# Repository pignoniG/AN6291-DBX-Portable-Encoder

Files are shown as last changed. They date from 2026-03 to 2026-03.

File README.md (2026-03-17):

AN6291 based DBX Portable Encoder with premplifier for electrect micropones.
Beware, for reliability (aka avoid switches), this can only perform as an encoder.

BOM -> https://pignonig.github.io/AN6291-DBX-Portable-Encoder/AN6291_encoder/bom/ibom.html

Online kikad visualization -> https://kicanvas.org/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

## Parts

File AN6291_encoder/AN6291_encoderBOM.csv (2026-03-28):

Reference | Qty | Value | JLCPCB Part | Footprint | Datasheet
C7,C16 | 2 | 330pf |  | Capacitor_SMD:C_0805_2012Metric | ~
C25,C31 | 2 | 2.7nF |  | Capacitor_SMD:C_0805_2012Metric | ~
C8,C9,C14,C15 | 4 | 3.3nf |  | Capacitor_SMD:C_0805_2012Metric | ~
C23,C26,C28,C32 | 4 | 6.8nf |  | Capacitor_SMD:C_0805_2012Metric | ~
C20,C22 | 2 | 10nf |  | Capacitor_SMD:C_0805_2012Metric | ~
C5,C18,C19,C21 | 4 | 33nf |  | Capacitor_SMD:C_0805_2012Metric | ~
C27,C29 | 2 | 0.1uf |  | Capacitor_SMD:C_1206_3216Metric | ~
C46,C47 | 2 | 100nf |  | Capacitor_SMD:C_1206_3216Metric | ~
C10,C11,C12,C13 | 4 | 100n |  | Capacitor_SMD:C_1206_3216Metric | ~
C6,C17 | 2 | 0.47uf |  | Capacitor_SMD:C_1206_3216Metric | ~
C4 | 1 | 1uf |  | Capacitor_SMD:C_0805_2012Metric | ~
C1,C2,C39,C40,C43,C44 | 6 | 10uf |  | Capacitor_SMD:C_1206_3216Metric | ~
C3,C33,C34,C35,C36,C38,C41,C42,C45,C50 | 10 | 10uf |  | Capacitor_SMD:C_0805_2012Metric | ~
C24,C30 | 2 | 22uf |  | Capacitor_SMD:C_1206_3216Metric | ~
C37 | 1 | 100uf |  | Capacitor_THT:CP_Radial_D10.0mm_P5.00mm | ~
R37,R48,R49,R58,R59,R60,R61 | 7 | 100R | C17408 | Resistor_SMD:R_0805_2012Metric | ~
R33,R35,R40,R42 | 4 | 270R | C17590 | Resistor_SMD:R_0805_2012Metric | ~
R22,R29 | 2 | 330R | C17630 | Resistor_SMD:R_0805_2012Metric | ~
R20,R21 | 2 | 560R | C28636 | Resistor_SMD:R_0805_2012Metric | ~
R1,R2,R19 | 3 | 1k | C17513 | Resistor_SMD:R_0805_2012Metric | ~
R64,R65 | 2 | 1k | C17513 | Resistor_SMD:R_0805_2012Metric | ~
R36,R41 | 2 | 2k | C17604 | Resistor_SMD:R_0805_2012Metric | ~
RV1 | 1 | 2k |  | Potentiometer_SMD:Potentiometer_Vishay_TS53YL_Vertical | ~
R4,R17 | 2 | 3.3K | C26010 | Resistor_SMD:R_0805_2012Metric | ~
R8,R14,R50,R53 | 4 | 4.7k | C17673 | Resistor_SMD:R_0805_2012Metric | ~
R6,R16 | 2 | 6.8k | C17772 | Resistor_SMD:R_0805_2012Metric | ~
R3,R18 | 2 | 10k | C17414 | Resistor_SMD:R_0805_2012Metric | ~
R23,R26,R27,R32 | 4 | 15k | C17475 | Resistor_SMD:R_0805_2012Metric | ~
R30,R38 | 2 | 22k | C17560 | Resistor_SMD:R_0805_2012Metric | ~
R7,R10,R13,R15 | 4 | 33k | C17633 | Resistor_SMD:R_0805_2012Metric | ~
R24,R31 | 2 | 51k | C17737 | Resistor_SMD:R_0805_2012Metric | ~
R25,R28 | 2 | 51k | C17737 | Resistor_SMD:R_0805_2012Metric | ~
R34,R39 | 2 | 56k | C17756 | Resistor_SMD:R_0805_2012Metric | ~
R51,R52,R62,R63 | 4 | 100k | C149504 | Resistor_SMD:R_0805_2012Metric | ~
R9,R11 | 2 | 150k | C17470 | Resistor_SMD:R_0805_2012Metric | ~
R54,R55,R56,R57 | 4 | 200k | C17539 | Resistor_SMD:R_0805_2012Metric | ~
R5,R12 | 2 | 270k | C17589 | Resistor_SMD:R_0805_2012Metric | ~
J3 | 1 | batt |  | Connector_PinHeader_2.54mm:PinHeader_1x02_P2.54mm_Vertical | ~
Q3,Q6 | 2 | BC848 |  | Package_TO_SOT_SMD:SOT-23 | http://www.infineon.com/dgdl/Infineon-BC847SERIES_BC848SERIES_BC849SERIES_BC850SERIES-DS-v01_01-en.pdf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
Q4,Q5 | 2 | BCV62 |  | Package_TO_SOT_SMD:SOT-143 | https://assets.nexperia.com/documents/data-sheet/BCV62.pdf
F1 | 1 | Fuse_Small |  | Fuse:Fuse_1206_3216Metric_Pad1.42x1.75mm_HandSolder | ~
J4 | 1 | input line |  | LIB_JY039-5P__FC68133_:JY0395PFC68133 | https://www.cliffuk.co.uk/products/jacksockets/fc68131.pdf
J1 | 1 | input mic |  | LIB_JY039-5P__FC68133_:JY0395PFC68133 | https://www.cliffuk.co.uk/products/jacksockets/fc68131.pdf
H1,H2,H3,H4 | 4 | MountingHole |  | MountingHole:MountingHole_3.2mm_M3_DIN965_Pad_TopBottom | ~
Q1,Q2 | 2 | NPN |  | Package_TO_SOT_THT:TO-92 | KSC1845
U3,U4 | 2 | OPA1612AxD |  | Package_SO:SOIC-8_3.9x4.9mm_P1.27mm | http://www.ti.com/lit/ds/symlink/opa1612.pdf
J2 | 1 | output |  | Connector_Molex:Molex_KK-254_AE-6410-04A_1x04_P2.54mm_Vertical | ~
S1 | 1 | SL19-123 |  | SL19-123:SL19123 | https://www.tme.eu/Document/8790ddf534d60e194ea4328cb05e27d2/sl19123.pdf
TP1,TP3 | 2 | TestPoint |  | Connector_PinHeader_1.00mm:PinHeader_1x01_P1.00mm_Vertical | ~
U1 | 1 | ~ |  | Package_DIP:DIP-22_W10.16mm_LongPads

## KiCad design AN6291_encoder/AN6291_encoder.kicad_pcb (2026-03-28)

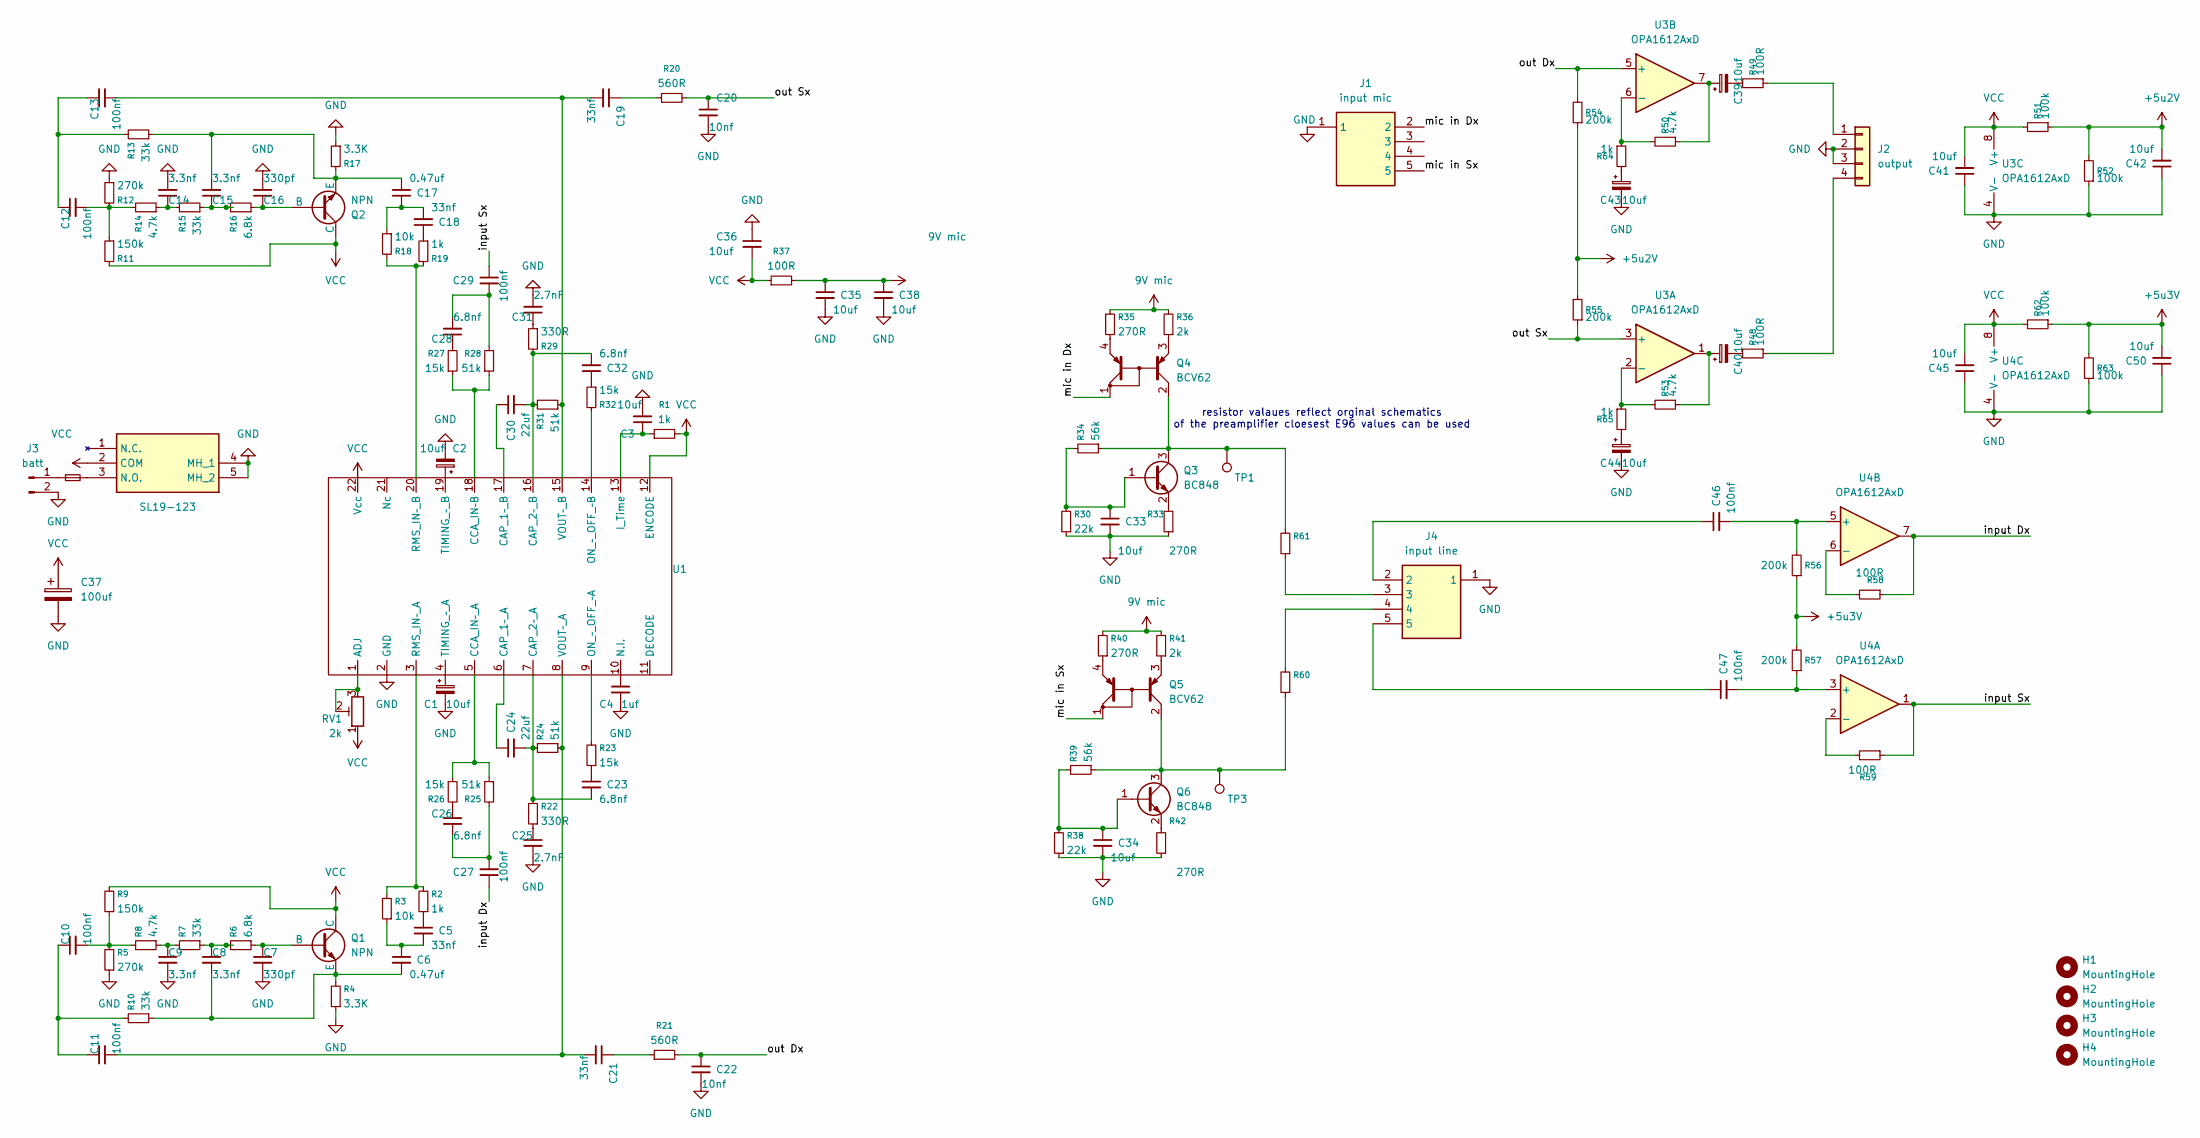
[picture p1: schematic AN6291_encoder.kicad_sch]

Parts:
C1, C2, C39, C40, C43, C44: 10uf; C_1206_3216Metric
C3, C33, C34, C35, C36, C38, C41, C42, C45, C50: 10uf; C_0805_2012Metric
C4: 1uf; C_0805_2012Metric
C5, C18, C19, C21: 33nf; C_0805_2012Metric
C6, C17: 0.47uf; C_1206_3216Metric
C7, C16: 330pf; C_0805_2012Metric
C8, C9, C14, C15: 3.3nf; C_0805_2012Metric
C10, C11, C12, C13, C27, C29, C46, C47: 100nf; C_1206_3216Metric
C20, C22: 10nf; C_0805_2012Metric
C23, C26, C28, C32: 6.8nf; C_0805_2012Metric
C24, C30: 22uf; C_1206_3216Metric
C25, C31: 2.7nF; C_0805_2012Metric
C37: 100uf; CP_Radial_D10.0mm_P5.00mm
F1: Fuse_Small; Fuse_1206_3216Metric_Pad1.42x1.75mm_HandSolder
H1, H2, H3, H4: MountingHole; MountingHole_3.2mm_M3_DIN965_Pad_TopBottom
J1: input mic; JY0395PFC68133; Manufacturer_Part_Number JY039-5P (FC68133)
J2: output; Molex_KK-254_AE-6410-04A_1x04_P2.54mm_Vertical
J3: batt; PinHeader_1x02_P2.54mm_Vertical
J4: input line; JY0395PFC68133; Manufacturer_Part_Number JY039-5P (FC68133)
Q1, Q2: NPN; TO-92
Q3, Q6: BC848; SOT-23
Q4, Q5: BCV62; SOT-143
R1, R2, R19, R64, R65: 1k; R_0805_2012Metric; JLCPCB Part C17513
R3, R18: 10k; R_0805_2012Metric; JLCPCB Part C17414
R4, R17: 3.3K; R_0805_2012Metric; JLCPCB Part C26010
R5, R12: 270k; R_0805_2012Metric; JLCPCB Part C17589
R6, R16: 6.8k; R_0805_2012Metric; JLCPCB Part C17772
R7, R10, R13, R15: 33k; R_0805_2012Metric; JLCPCB Part C17633
R8, R14, R50, R53: 4.7k; R_0805_2012Metric; JLCPCB Part C17673
R9, R11: 150k; R_0805_2012Metric; JLCPCB Part C17470
R20, R21: 560R; R_0805_2012Metric; JLCPCB Part C28636
R22, R29: 330R; R_0805_2012Metric; JLCPCB Part C17630
R23, R26, R27, R32: 15k; R_0805_2012Metric; JLCPCB Part C17475
R24, R25, R28, R31: 51k; R_0805_2012Metric; JLCPCB Part C17737
R30, R38: 22k; R_0805_2012Metric; JLCPCB Part C17560
R33, R35, R40, R42: 270R; R_0805_2012Metric; JLCPCB Part C17590
R34, R39: 56k; R_0805_2012Metric; JLCPCB Part C17756
R36, R41: 2k; R_0805_2012Metric; JLCPCB Part C17604
R37, R48, R49, R58, R59, R60, R61: 100R; R_0805_2012Metric; JLCPCB Part C17408
R51, R52, R62, R63: 100k; R_0805_2012Metric; JLCPCB Part C149504
R54, R55, R56, R57: 200k; R_0805_2012Metric; JLCPCB Part C17539
RV1: 2k; Potentiometer_Vishay_TS53YL_Vertical
S1: SL19-123; SL19123; Manufacturer_Part_Number SL19-123
TP1, TP3: TestPoint; PinHeader_1x01_P1.00mm_Vertical
U1: DIP-22_W10.16mm_LongPads
U3, U4: OPA1612AxD; SOIC-8_3.9x4.9mm_P1.27mm

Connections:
9V mic: C35.1, C38.1, R35.2, R36.2, R37.2, R40.2, R41.2
+5u2V: C42.2, R51.1, R52.2, R54.1, R55.2
+5u3V: C50.2, R56.1, R57.2, R62.1, R63.2
/input Dx: C27.1, R58.1, U4.7
/input Sx: C29.1, R59.1, U4.1
/mic in Dx: J1.2, Q4.1 (C2)
/mic in Sx: J1.5, Q5.1 (C2)
/out Dx: C22.1, R21.2, R54.2, U3.5 (+)
/out Sx: C20.1, R20.2, R55.1, U3.3 (+)
GND: C1.2, C2.2, C3.2, C4.2, C7.2, C9.2, C14.2, C16.2, C20.2, C22.2, C25.2, C31.2, C33.2, C34.2, C35.2, C36.1, C37.2, C38.2, C41.1, C42.1, C43.2, C44.2, C45.1, C50.1, J1.1, J2.2, J2.3, J3.2, J4.1, R4.1, R5.1, R12.1, R17.1, R30.1, R33.1, R38.1, R42.1, R52.1, R63.1, S1.4 (MH_1), S1.5 (MH_2), U1.2 (GND), U3.4 (V-), U4.4 (V-)
unnamed: C5.1, R2.1
unnamed: C5.2, C6.1, R3.1
unnamed: C8.1, R6.2, R7.1
unnamed: C9.1, R7.2, R8.1
unnamed: C10.1, C11.1, R10.2
unnamed: C10.2, R5.2, R8.2, R9.1
unnamed: C12.1, C13.1, R13.2
unnamed: C12.2, R11.1, R12.2, R14.2
unnamed: C14.1, R14.1, R15.2
unnamed: C15.1, R15.1, R16.2
unnamed: C17.1, C18.2, R18.1
unnamed: C18.1, R19.1
unnamed: C19.1, R20.1
unnamed: C21.1, R21.1
unnamed: C23.1, R23.1
unnamed: C25.1, R22.1
unnamed: C26.1, R26.2
unnamed: C26.2, C27.2, R25.2
unnamed: C28.1, R27.2
unnamed: C28.2, C29.2, R28.2
unnamed: C31.1, R29.1
unnamed: C32.1, R32.1
unnamed: C39.1, R50.1, U3.7
unnamed: C39.2, R49.2
unnamed: C40.1, R53.1, U3.1
unnamed: C40.2, R48.2
unnamed: C43.1, R64.2
unnamed: C44.1, R65.2
unnamed: C46.1, J4.2
unnamed: C47.1, J4.5
unnamed: J2.1, R49.1
unnamed: J2.4, R48.1
unnamed: F1.1, J3.1
unnamed: J4.3, R61.1
unnamed: J4.4, R60.2
unnamed: C7.1, Q1.3 (B), R6.1
unnamed: C6.2, C8.2, Q1.1 (E), R4.2, R10.1
unnamed: C16.1, Q2.3 (B), R16.1
unnamed: C15.2, C17.2, Q2.1 (E), R13.1, R17.2
unnamed: C33.1, Q3.1 (B), R30.2, R34.2
unnamed: Q3.3 (C), Q4.2 (C1), R34.1, R61.2, TP1.1
unnamed: Q3.2 (E), R33.2
unnamed: Q4.3 (E1), R36.1
unnamed: Q4.4 (E2), R35.1
unnamed: Q5.2 (C1), Q6.3 (C), R39.1, R60.1, TP3.1
unnamed: Q5.3 (E1), R41.1
unnamed: Q5.4 (E2), R40.1
unnamed: C34.1, Q6.1 (B), R38.2, R39.2
unnamed: Q6.2 (E), R42.2
unnamed: F1.2, S1.3 (N.O.)
unnamed: RV1.2, RV1.3, U1.1 (ADJ)
unnamed: C24.1, U1.6 (CAP_1–_A)
unnamed: C30.1, U1.17 (CAP_1–_B)
unnamed: C23.2, C24.2, R22.2, R24.2, U1.7 (CAP_2–_A)
unnamed: C30.2, C32.2, R29.2, R31.2, U1.16 (CAP_2–_B)
unnamed: R27.1, R28.1, U1.18 (CCA_IN–B)
unnamed: R25.1, R26.1, U1.5 (CCA_IN–_A)
unnamed: C3.1, R1.1, U1.13 (I_Time)
unnamed: C4.1, U1.10 (N.I.)
unnamed: R23.2, U1.9 (ON_–_OFF_–A)
unnamed: R32.2, U1.14 (ON_–_OFF_–B)
unnamed: R2.2, R3.2, U1.3 (RMS_IN–_A)
unnamed: R18.2, R19.2, U1.20 (RMS_IN–_B)
unnamed: C1.1, U1.4 (TIMING_–_A)
unnamed: C2.1, U1.19 (TIMING_–_B)
unnamed: C11.2, C21.2, R24.1, U1.8 (VOUT–_A)
unnamed: C13.2, C19.2, R31.1, U1.15 (VOUT–_B)
unnamed: R53.2, R65.1, U3.2 (-)
unnamed: R50.2, R64.1, U3.6 (-)
unnamed: C47.2, R57.1, U4.3 (+)
unnamed: R59.2, U4.2 (-)
unnamed: C46.2, R56.2, U4.5 (+)
unnamed: R58.2, U4.6 (-)
VCC: C36.2, C37.1, C41.2, C45.2, Q1.2 (C), Q2.2 (C), R1.2, R9.2, R11.2, R37.1, R51.2, R62.2, RV1.1, S1.2 (COM), U1.12 (ENCODE), U1.22 (Vcc), U3.8 (V+), U4.8 (V+)

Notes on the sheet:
resistor valaues reflect orginal schematics of the preamplifier cloesest E96 values can be used

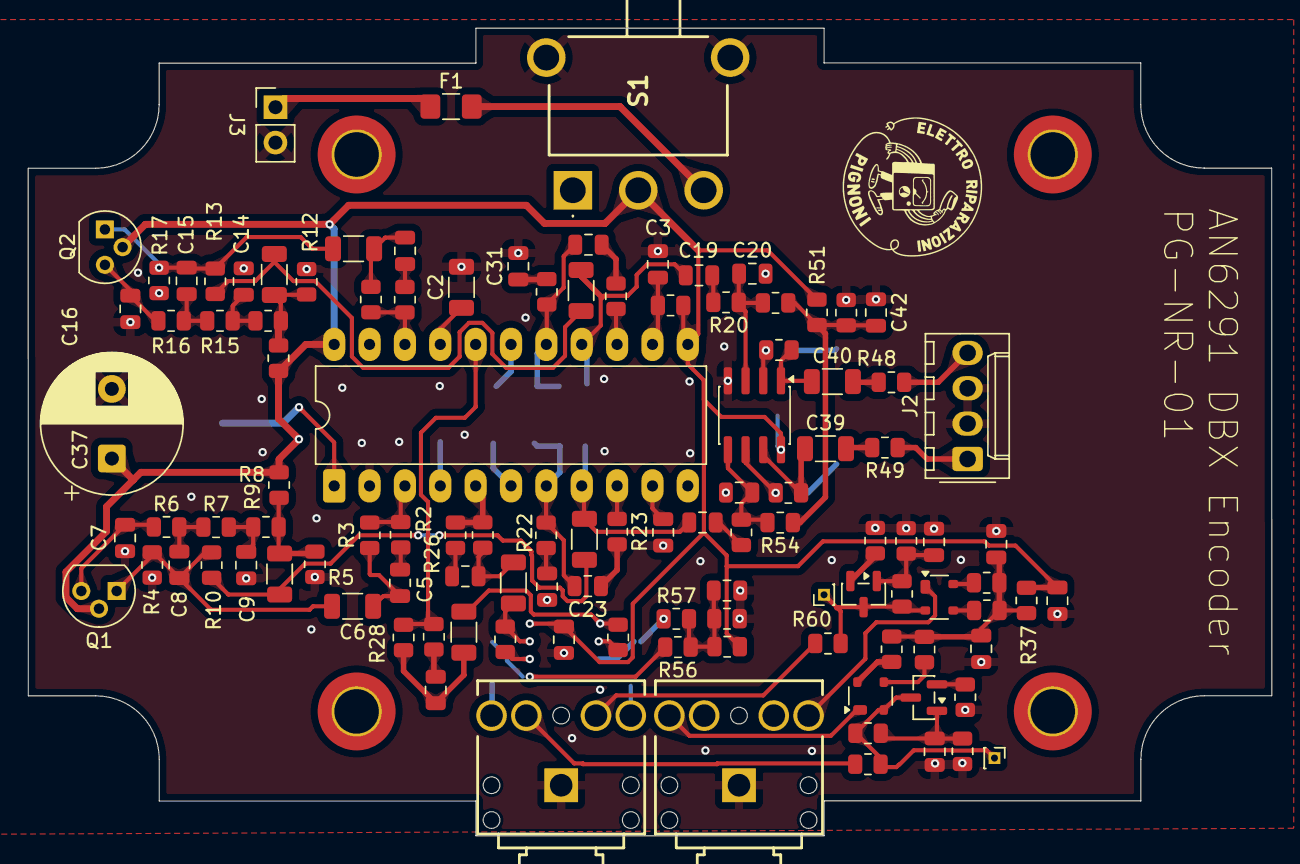
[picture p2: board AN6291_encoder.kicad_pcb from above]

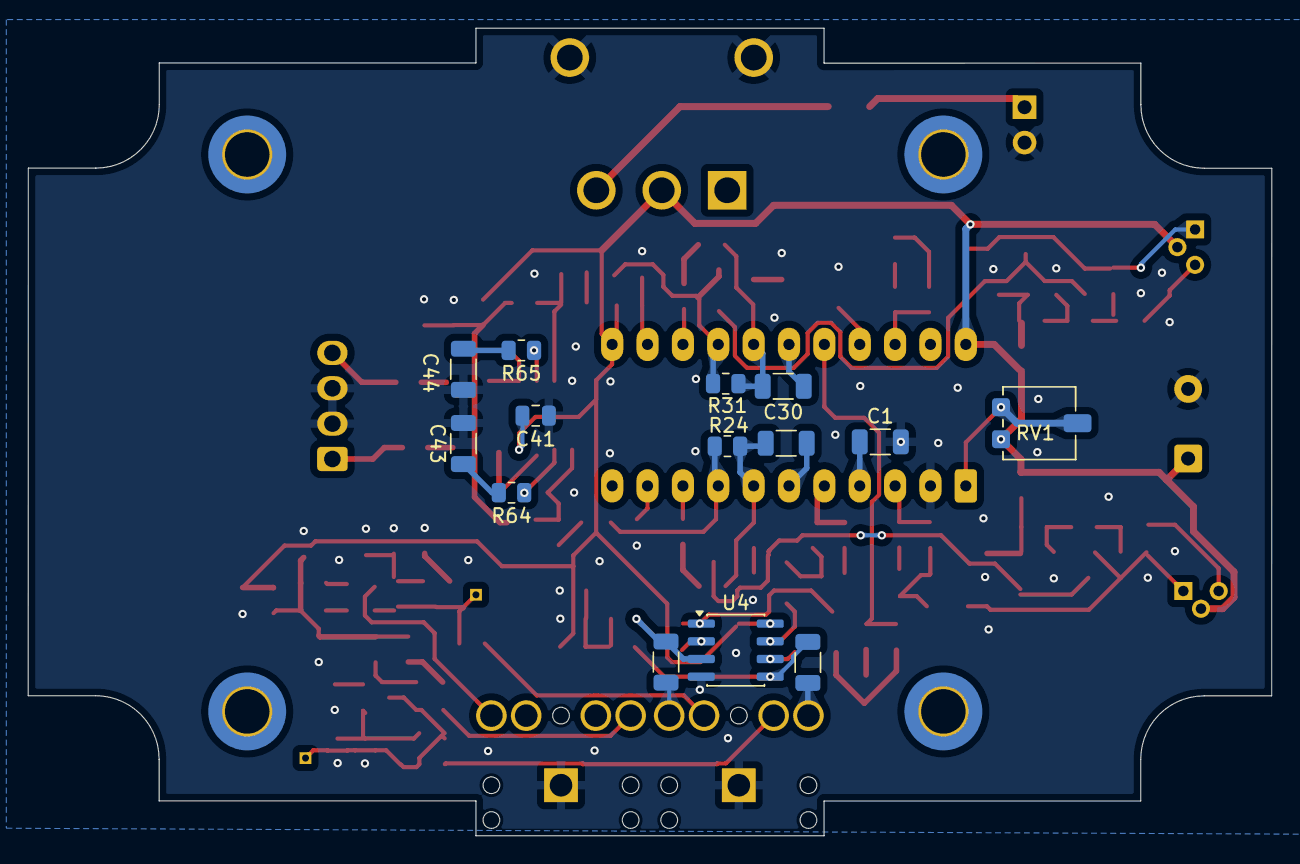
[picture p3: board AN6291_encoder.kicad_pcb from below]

Board: 2 copper layers, 89.3 x 58.0 mm, 130 parts (14 on the bottom side), 84 nets.

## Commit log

2026-03-16 Add description for AN6291 based DBX Portable Encoder
2026-03-22 Removed voltage regulator for microphone supply now powered from 9v battery for lower noise
    [AN6291_encoder.kicad_pcb, AN6291_encoder.kicad_sch]
2026-03-28 rev B
    [AN6291_encoder-B_Cu.gbr, AN6291_encoder-B_Mask.gbr, AN6291_encoder-B_Paste.gbr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]
